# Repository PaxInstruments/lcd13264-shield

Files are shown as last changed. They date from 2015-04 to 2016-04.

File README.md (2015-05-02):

# Pax Instruments
# LCD12364-shield

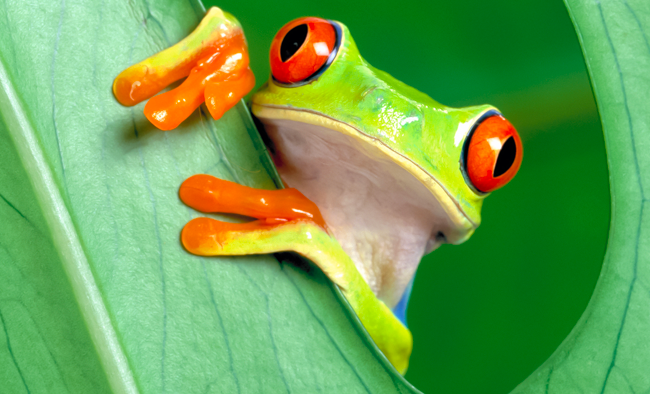
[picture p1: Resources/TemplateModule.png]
  
[Pax Instruments Template Module](<link to store page>)

## Overview
The Pax Instruments LCD12364-shield is an Arduino shield for the Pax Instruments LCD23164 graphic LCD. You can [purchase this item in our store](http://paxinstruments.com/products/sku1003/).

## Repository Contents
- __Datasheets__ - Datasheets for relevant components and parts
- __Electronics__ - All PCB and schematic design files
- __Enclosure__ - Enclosure 3D design files
- __Firmware__ - Firmware, libraries, and examples
- __Production__ - Manufacturing resources
- __Resources__ - Other resources

## Product Versions

## License Information
```
Place the license statement here
```

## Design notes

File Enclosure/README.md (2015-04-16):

# Pax Instruments
# LCD12364-shield Enclosure

Developed by <person(s) name> for [Pax Instruments](http://paxinstruments.com/), an original design.

## Overview
This is the enclsoure for the Pax Instruments LCD12364-shield designed in <software package>. STL files are included for your convenience.

## License
```
Place the license statement here
```

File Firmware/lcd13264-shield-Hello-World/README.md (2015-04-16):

# Pax Instruments
# LCD12364-shield Firmware

Developed by <person(s) name> for [Pax Instruments](http://paxinstruments.com/) based on Arduino and other Open Source libraries.

## Overview
There is no firmware required for the Pax Instruments LCD12364-shield.

## Required libraries
- Link to a forked Pax Instruments version
- of any  libraries used

## Installation
1. Copy libraryName into your <Arduino folder>/libraries/
2. Restart the ARduino IDE

## Example 1 - Hello, world!
```
void setup() {
    // The setup function. This runs once.
}

void loop() {
    // The loop function. This restarts when complete.
}
```

## History
__v0.2: 2015-02-22 by Charles Edward Pax__

- Major change 1
- Major change 2

__v0.1: 2015-02-20 by Charles Edward Pax__

- Major change 1
- Major change 2

## License
```
Place the license statement here
```

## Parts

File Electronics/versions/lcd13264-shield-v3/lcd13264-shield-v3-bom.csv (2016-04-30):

Qty | Value | Device | Package | Parts | Description | MPN | OC_DIGIKEY | PROD_ID | VALUE
1 |  | M08 | 1X08_ROUND | JP1 | Header 8
2 |  | TXB0104PWRSOIC14 | SO14 | U2, U3 | 4-Bit Bi-Directional Level Shifter |  |  | IC-11329
5 | 100nF | SPARKFUN-CAPACITORS_CAP0603-CAP | SPARKFUN-CAPACITORS_0603-CAP | C3, C4, C5, C6, C21 | Capacitor | CL10B104KO8NNNC | 1276-1005-2-ND
6 | 10k | SPARKFUN-RESISTORS_RESISTOR0603-RES | SPARKFUN-RESISTORS_0603-RES | R1, R8, R11, R12, R15, R16 | Resistor | RC1608J103CS | 1276-5086-2-ND
4 | 1uF | SPARKFUN-CAPACITORS_CAP0603-CAP | SPARKFUN-CAPACITORS_0603-CAP | C1, C2, C35, C36 | Capacitor | LMK107B7105KA-T | 587-1242-2-ND
2 | 3.3R | SPARKFUN-RESISTORS_RESISTOR0603-RES | SPARKFUN-RESISTORS_0603-RES | R2, R19 | Resistor
1 | ARDUINO_R3_SHIELDUNO_R3_SHIELD_NOLABELS_LOCK | ARDUINO_R3_SHIELDUNO_R3_SHIELD_NOLABELS_LOCK | UNO_R3_SHIELD_NOLABELS_LOCK | J3 | Shield form compatible with the Arduino Uno R3.
2 | FH12-12S-1S | FH12-12S-1S | FH12-12S-1SH | X1, X2
22 | JUMPER-PAD-2-NC_BY_PASTE | JUMPER-PAD-2-NC_BY_PASTE | PAD-JUMPER-2-NC_BY_PASTE_YES_SILK | SJ1, SJ2, SJ3, SJ4, SJ5, SJ6, SJ7, SJ8, SJ9, SJ10, SJ11, SJ12, SJ13, SJ14, SJ19, SJ20, SJ21, SJ22, SJ23, SJ24, SJ25, SJ26
1 | LG132643-DG | LG132643-DG | LG132643-DG | U$5 |  | LG132643-DW
1 | MICRO-SDCARD-CONNECTOR-3300060P1 | MICRO-SDCARD-CONNECTOR-3300060P1 | 9P-SMD-W-RING | J1 | Micro SD Card
1 | PNP-500mA | TRANSISTOR-PNP-DDTB142TC | SOT23-3 | Q1 | PNP transistor with base resistor. |  |  | TRANS-11479 | PNP-500mA
6 | SWITCH-MOMENTARY-2SMD | SWITCH-MOMENTARY-2SMD | TACTILE_SWITCH_SMD | S1, S2, S3, S4, S5, S6 | Various NO switches- pushbuttons, reed, etc

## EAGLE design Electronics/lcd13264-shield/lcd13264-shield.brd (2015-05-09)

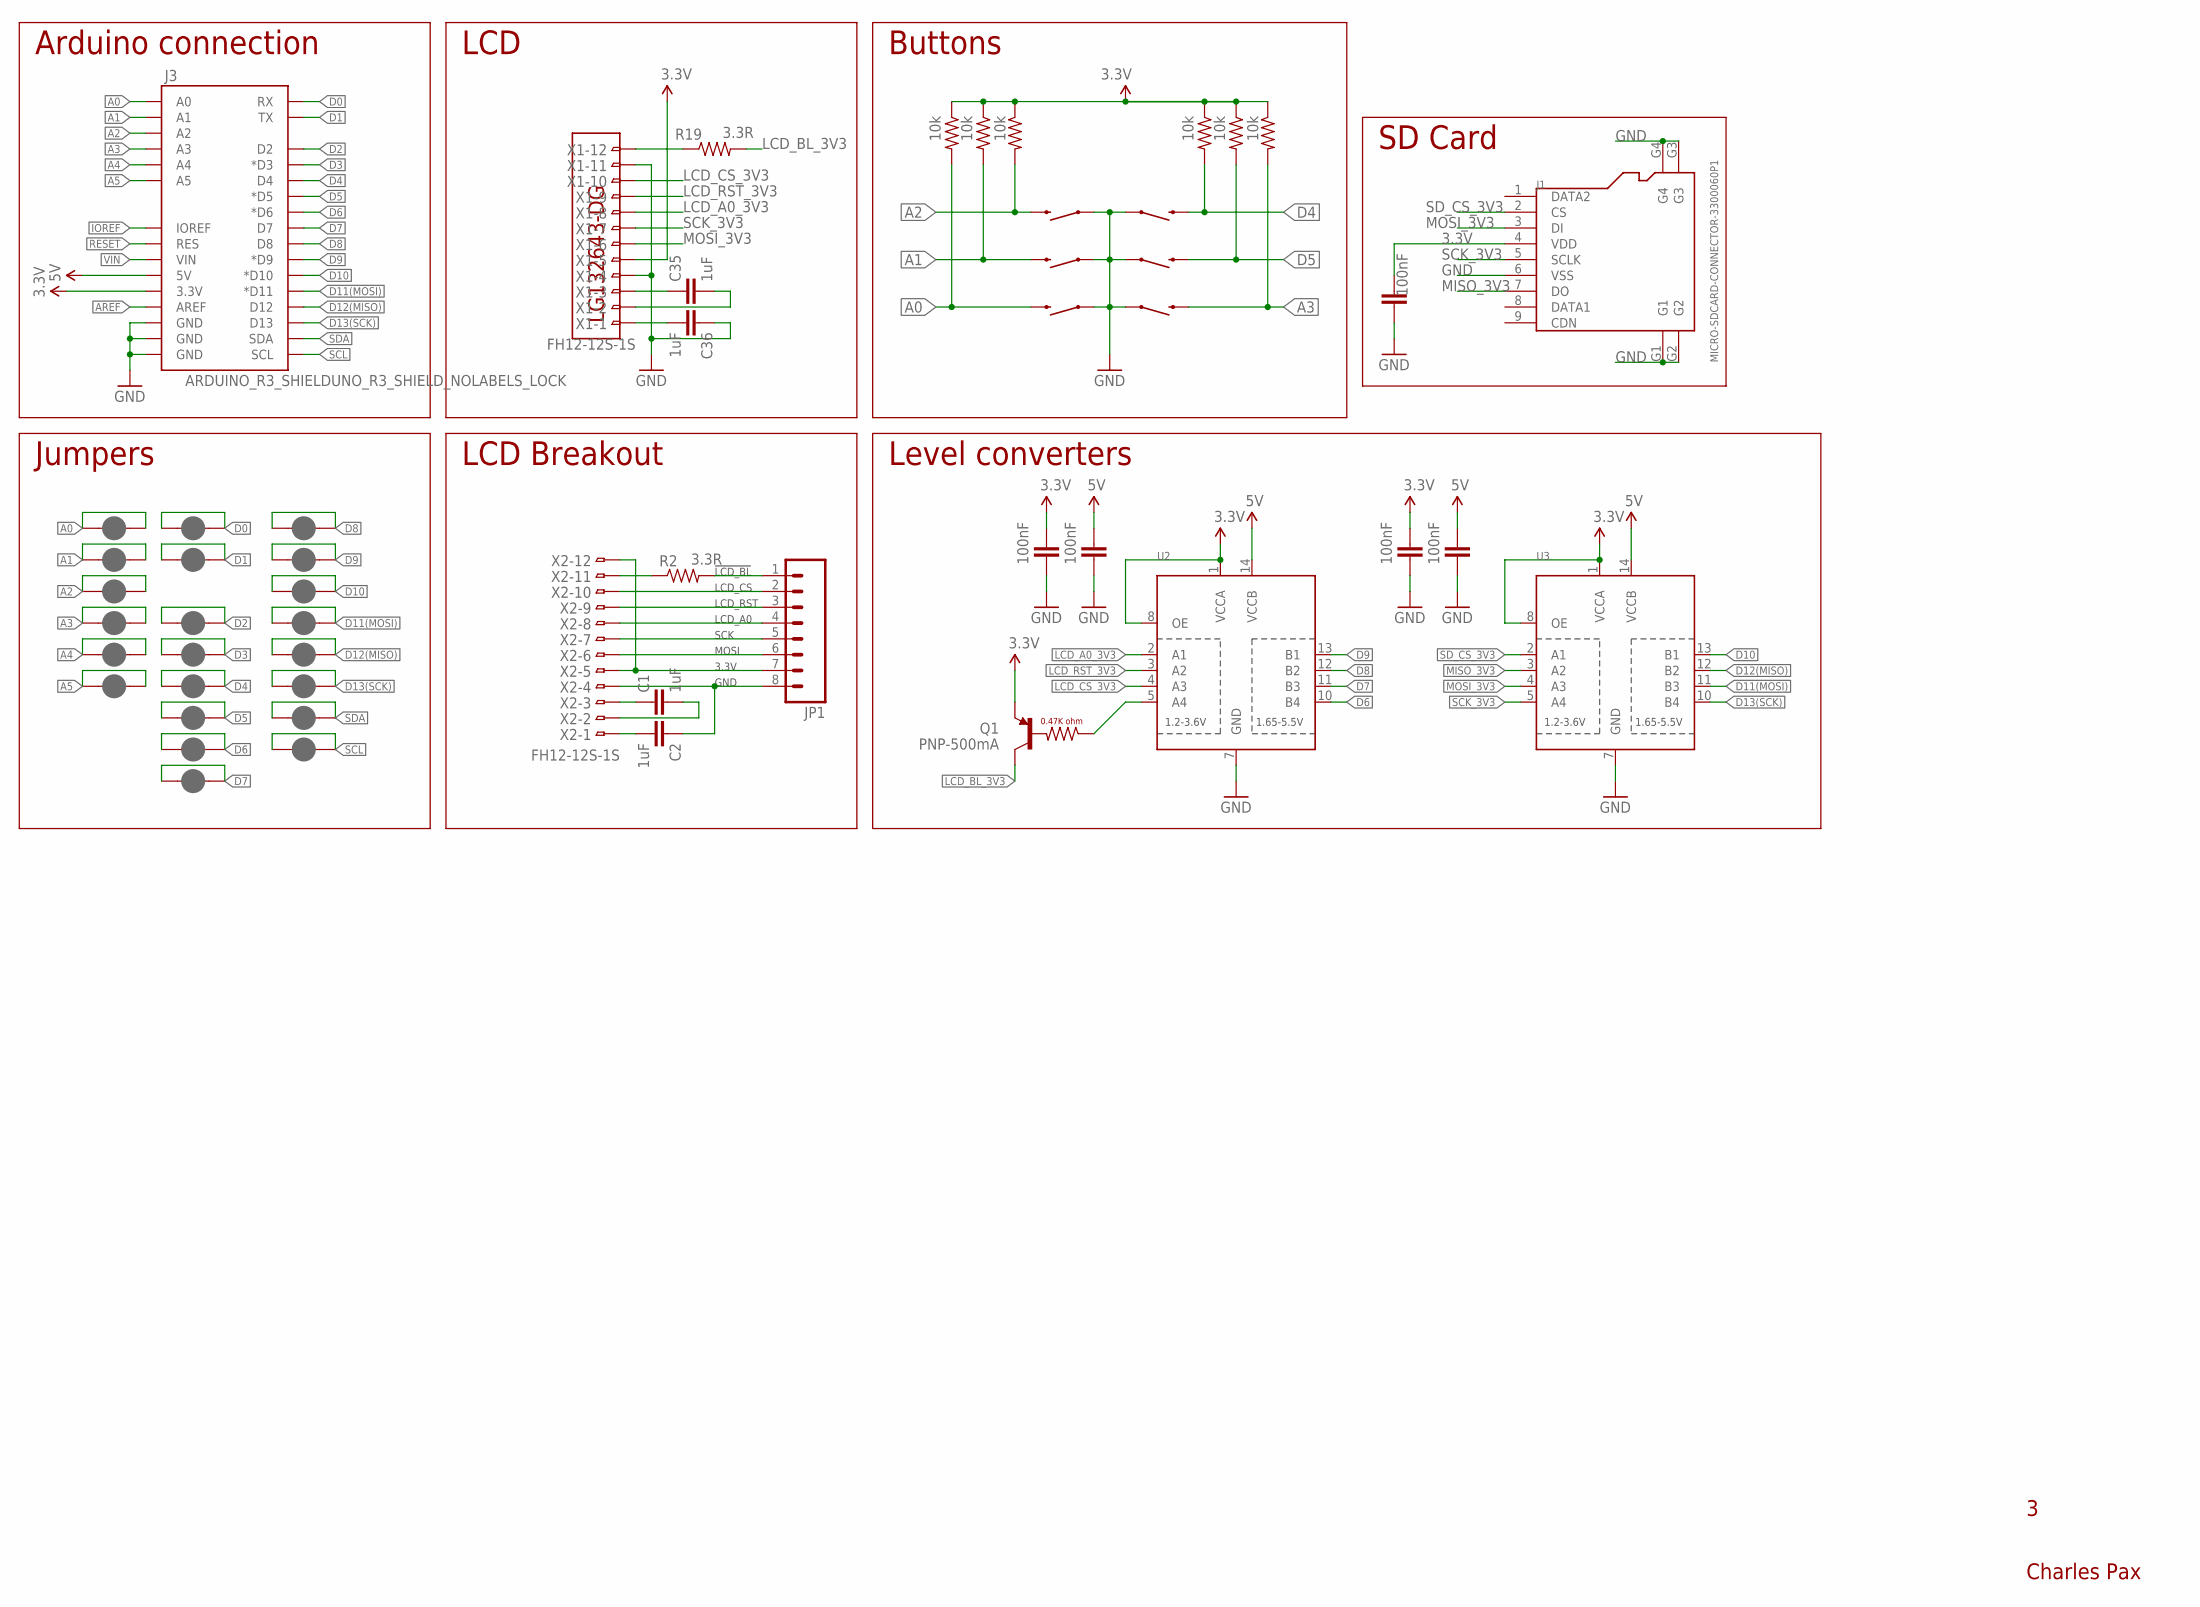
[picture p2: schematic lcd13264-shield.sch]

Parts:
C1, C2, C35, C36: 1uF; SPARKFUN-CAPACITORS_0603-CAP; MPN LMK107B7105KA-T
C3, C4, C5, C6, C21: 100nF; SPARKFUN-CAPACITORS_0603-CAP; MPN CL10B104KO8NNNC
J1: MICRO-SDCARD-CONNECTOR-3300060P1; 9P-SMD-W-RING
J3: ARDUINO_R3_SHIELDUNO_R3_SHIELD_NOLABELS_LOCK; UNO_R3_SHIELD_NOLABELS_LOCK
JP1: M08; 1X08_ROUND
Q1: PNP-500mA; SOT23-3; MPN DDTB142TC
R1, R8, R11, R12, R15, R16: 10k; SPARKFUN-RESISTORS_0603-RES; MPN RC1608J103CS
R2, R19: 3.3R; SPARKFUN-RESISTORS_0603-RES
S1, S2, S3, S4, S5, S6: SWITCH-MOMENTARY-2SMD; TACTILE_SWITCH_SMD
SJ1, SJ2, SJ3, SJ4, SJ5, SJ6, SJ7, SJ8, SJ9, SJ10, SJ11, SJ12, SJ13, SJ14, SJ19, SJ20, SJ21, SJ22, SJ23, SJ24, SJ25, SJ26: JUMPER-PAD-2-NC_BY_PASTE; PAD-JUMPER-2-NC_BY_PASTE_YES_SILK
U2, U3: TXB0104PWRSOIC14; SO14; MPN TXB0104DR
U$5: LG132643-DG; MPN LG132643-DW
X1, X2: FH12-12S-1S; FH12-12S-1SH

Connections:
3.3V: C3.2, C5.2, C21.2, J1.4 (VDD), J3.3.3V, Q1.2 (E), R1.1, R8.1, R11.1, R12.1, R15.1, R16.1, U2.1 (VCCA), U2.8 (OE), U3.1 (VCCA), U3.8 (OE), X1.5
5V: C4.2, C6.2, J3.5V, U2.14 (VCCB), U3.14 (VCCB)
A0: J3.A0, R1.2, S6.3 (2), SJ10.1, SJ10.2
A1: J3.A1, R16.2, S5.3 (2), SJ7.1, SJ7.2
A2: J3.A2, R15.2, S4.3 (2), SJ11.1, SJ11.2
A3: J3.A3, R12.2, S1.3 (2), SJ12.1, SJ12.2
A4: J3.A4, SJ13.1, SJ13.2
A5: J3.A5, SJ14.1, SJ14.2
AREF: J3.AREF
D0: J3.RX, SJ8.1, SJ8.2
D1: J3.TX, SJ9.1, SJ9.2
D2: J3.D2, SJ3.1, SJ3.2
D3: J3.D3 (*D3), SJ4.1, SJ4.2
D4: J3.D4, R8.2, S3.3 (2), SJ5.1, SJ5.2
D5: J3.D5 (*D5), R11.2, S2.3 (2), SJ6.1, SJ6.2
D6: J3.D6 (*D6), SJ19.1, SJ19.2, U2.10 (B4)
D7: J3.D7, SJ20.1, SJ20.2, U2.11 (B3)
D8: J3.D8, SJ21.1, SJ21.2, U2.12 (B2)
D9: J3.D9 (*D9), SJ22.1, SJ22.2, U2.13 (B1)
D10: J3.D10 (*D10), SJ23.1, SJ23.2, U3.13 (B1)
D11(MOSI): J3.D11 (*D11), SJ24.1, SJ24.2, U3.11 (B3)
D12(MISO): J3.D12, SJ25.1, SJ25.2, U3.12 (B2)
D13(SCK): J3.D13, SJ26.1, SJ26.2, U3.10 (B4)
GND: C2.1, C3.1, C4.1, C5.1, C6.1, C21.1, C36.1, J1.6 (VSS), J1.G1, J1.G2, J1.G3, J1.G4, J3.GND@0 (GND), J3.GND@1 (GND), J3.GND@2 (GND), JP1.8, S1.1, S2.1, S3.1, S4.1, S5.1, S6.1, U2.7 (GND), U3.7 (GND), X1.4, X1.11, X2.4
IOREF: J3.IOREF
LCD_A0_3V3: U2.2 (A1), X1.8
LCD_BL_3V3: Q1.3 (C), R19.2
LCD_CS_3V3: U2.4 (A3), X1.10
LCD_RST_3V3: U2.3 (A2), X1.9
MISO_3V3: J1.7 (DO), U3.3 (A2)
MOSI_3V3: J1.3 (DI), U3.4 (A3), X1.6
unnamed: R19.1, X1.12
unnamed: C35.1, X1.3
unnamed: C35.2, X1.2
unnamed: C36.2, X1.1
unnamed: C1.1, X2.3
unnamed: C1.2, X2.2
unnamed: C2.2, X2.1
unnamed: R2.1, X2.11
unnamed: JP1.7, X2.5, X2.12
unnamed: JP1.1, R2.2
unnamed: JP1.2, X2.10
unnamed: JP1.3, X2.9
unnamed: JP1.4, X2.8
unnamed: JP1.5, X2.7
unnamed: JP1.6, X2.6
unnamed: Q1.1 (B), U2.5 (A4)
RESET: J3.RES
SCK_3V3: J1.5 (SCLK), U3.5 (A4), X1.7
SCL: J3.SCL, SJ2.1, SJ2.2
SDA: J3.SDA, SJ1.1, SJ1.2
SD_CS_3V3: J1.2 (CS), U3.2 (A1)
VIN: J3.VIN

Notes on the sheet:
LCD
Buttons
Charles Pax
SD Card
Arduino connection
LCD Breakout
GND
3.3V
MOSI
SCK
LCD_A0
LCD_RST
LCD_CS
!LCD_BL
Level converters
Jumpers

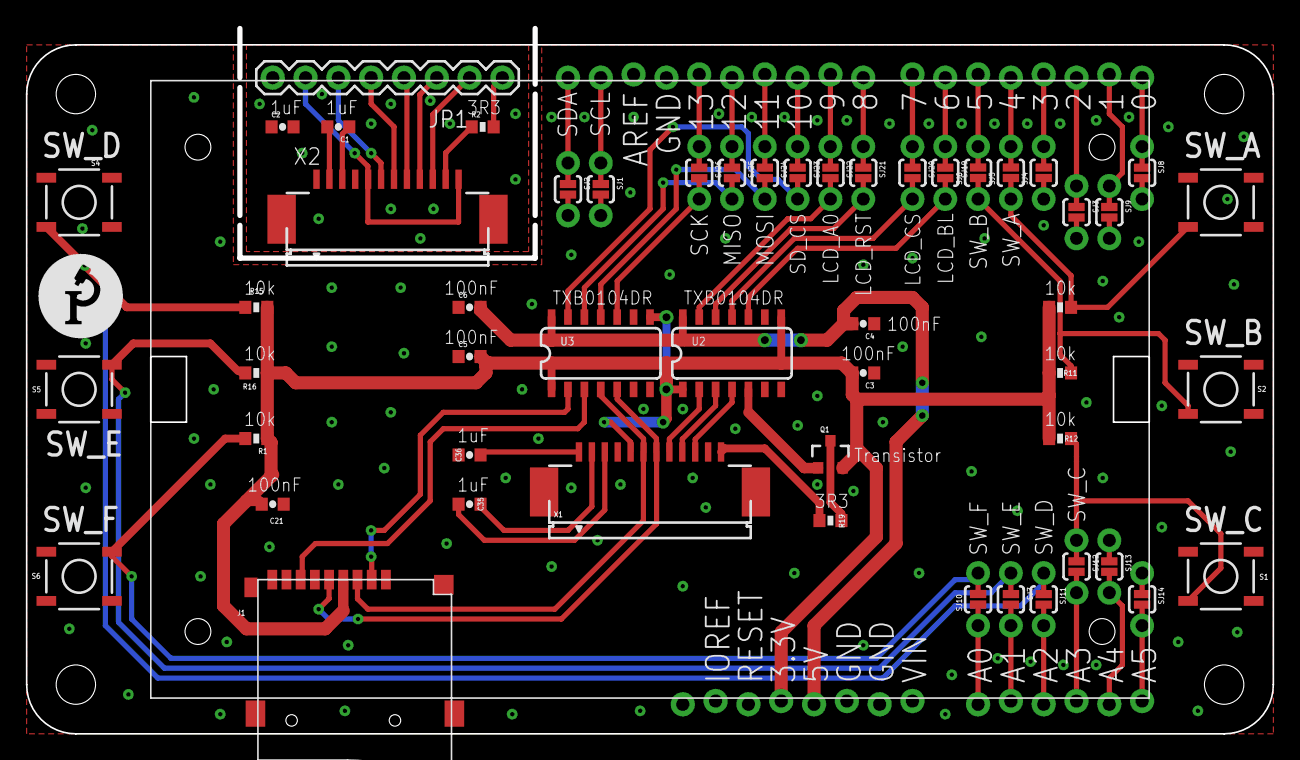
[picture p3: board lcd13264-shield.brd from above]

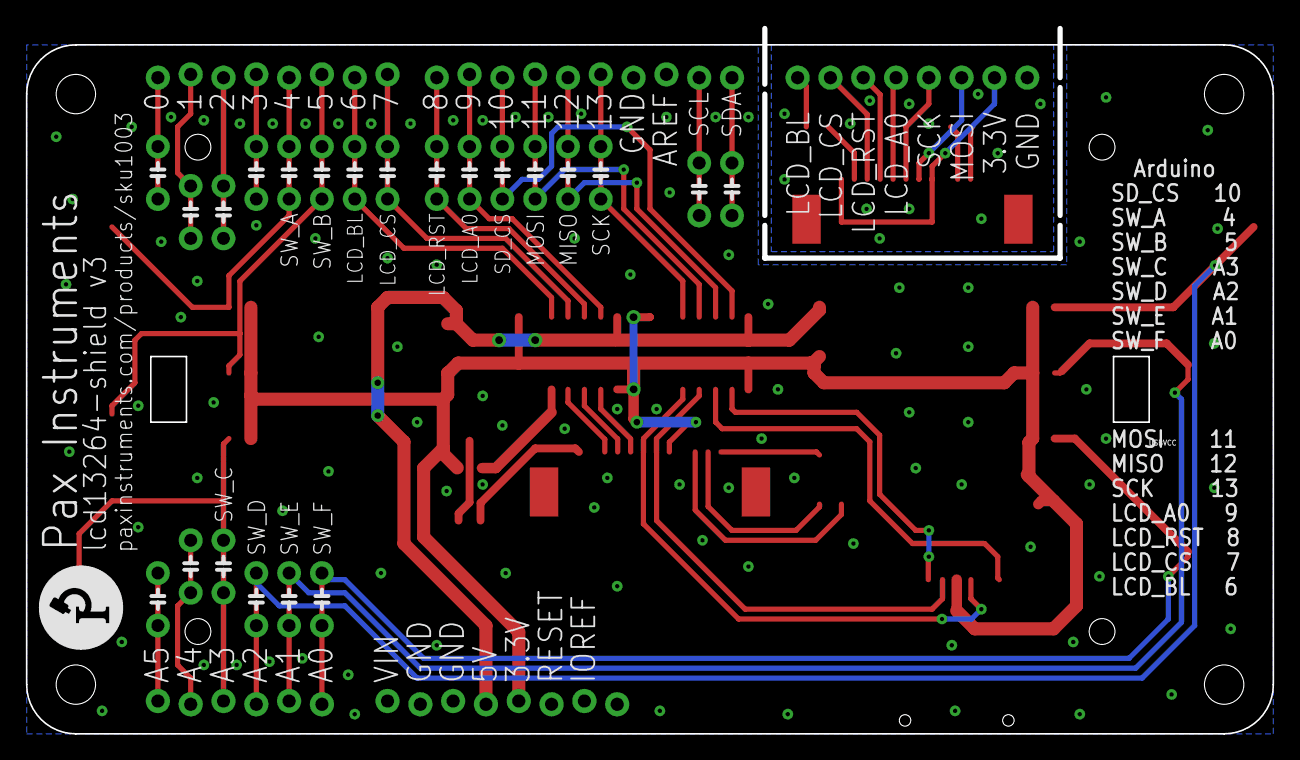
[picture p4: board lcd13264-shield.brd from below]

Board: 2 copper layers, 96.5 x 54.6 mm, 56 parts (2 on the bottom side), 49 nets.

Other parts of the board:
U$1, U$6: PAXINSTRUMENT_LOGO

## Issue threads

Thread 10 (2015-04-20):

Arduino footprint marking information

charlespax, 2015-04-20:
Make an Arduino shield footprint that only marks the location of holes and describes things. This would not be rendered in any way on the gerber files.

This will be helpful when moving to the jumpers rather than a complete Arduino footprint with silkscreen. See https://github.com/PaxInstruments/lcd13264-shield/issues/6

charlespax, 2015-04-26:
Design has Arduino pin markings.

Closed 2015-04-26.

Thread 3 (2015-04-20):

Header interference

charlespax, 2015-04-20:
Rotate the extra breakout board 1008 degrees, so the header can be soldered into place without interfering with the Arduino USB connector.
![Uploading Screen Shot 2015-04-20 at 16.33.38.png . . .]()

charlespax, 2015-04-20:
Done. Closing.

Closed 2015-04-20.

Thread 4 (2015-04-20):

Connection labels

charlespax, 2015-04-20:
Add a table to the silkscreen that correlates the Arduino pins with the shield functions.

Here is what they are in the schematic.
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

We can also label the pins with their function.
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

charlespax, 2015-04-20:
We can put this in a place that can be viewed while the shield is plugged into an Arduino.

charlespax, 2015-04-26:
Each IO pin has a label. There is a pin map table on the silkscreen.

Closed 2015-04-26.

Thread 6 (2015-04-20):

Pin configuration jumpers

charlespax, 2015-04-20:
It would be great if there were jumpers such that users have some degree of freedom to configure which pins are connected to which devices. We can place jumpers and extra through hole vias next to each arduino pin on the shield. The user can cut the trace and solder a jumper wire to their desired pin.

It would be cool if there were a nice place on the silkscreen where the user can write their new pin configuration.

charlespax, 2015-04-20:
Use these jumpers.

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

charlespax, 2015-04-26:
All I/O pins have jumpers.

Closed 2015-04-26.

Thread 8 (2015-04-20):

Symmetry

charlespax, 2015-04-20:
The arduinio can be made more symmetric on the shield. It looks like the top and bottom standoff tabs do not interfere with the pin headers.

charlespax, 2015-04-26:
I moved the Arduino such that mounting holes can go in the corners.

Closed 2015-04-26.

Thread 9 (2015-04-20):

Prototyping area

charlespax, 2015-04-20:
Add some through-hole and SMD prototyping pads to both sides of the PCB.

charlespax, 2015-04-26:
Meh. Ice boxing...

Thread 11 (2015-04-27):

Silkscreen issues

charlespax, 2015-04-27:
The logo overlaps the pin map. Move logo left.
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

Product name is on a hole. The P in Pax Instruments may be too close to the milled slot
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

Breakout board labels cover each other and on is on a solder pad.
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

The LCD connector and transistor are not labelled.
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

There is an old USBVCC label on the silkscreen.
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

Add labels to the breakout board bottom.
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

We have the room, so we may as well label the bottom side Arduino pins.
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

We can add drawings to the bottom to indicate how the pins are connected.
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

We should indicate the pin map is for Arduino pins.
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

Add lines to indicate which pads are for the same component. It could be confusing for beginners.
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

The pin map may be too close to the milled slot.
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

We should add function labels to the silkscreen.
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

charlespax, 2015-05-02:
Many of these problems are from Eagle using a proportional font in the interface, but a vector font in the CAM processor. See http://forum.sunstone.com/eagle-text-does-not-look-the-same-on-the-screen-and-pcb-t81.html.

charlespax, 2015-05-02:
Done.

Closed 2015-05-02.

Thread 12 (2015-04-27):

Transistor size

charlespax, 2015-04-27:
Maybe we should increase the resistor size. This would make it easier to solder.
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

charlespax, 2015-05-02:
Let's keep the size we have. People are soldering 0603 parts anyway.

Closed 2015-05-02.

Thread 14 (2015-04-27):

Breakout board snaps

charlespax, 2015-04-27:
This links between the breakout board and shield should be a hair smaller

charlespax, 2015-05-02:
Done.

Closed 2015-05-02.

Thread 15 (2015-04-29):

Update footprints

charlespax, 2015-04-29:
Make sure all the footprints are up-to-date. This specifically affects the LCD connector.

charlespax, 2015-05-02:
It looks like the LCD connector is up to date.

Closed 2015-05-02.

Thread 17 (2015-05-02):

Expose Arduino ports to putside world

charlespax, 2015-05-02:
We can move the Arduino board to an edge such that the shield and Arduino can be put into an enclosure and have the SD, USB, and power ports open to the outside.

Ice boxing...

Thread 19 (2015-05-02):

Hole in logo

charlespax, 2015-05-02:
The rendering of version 3 has a big via going right through the logo. We should move this.
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

charlespax, 2015-05-03:
Not a problem. Maybe fix in the next version. Ice Box.

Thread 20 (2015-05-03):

Backlight active low

charlespax, 2015-05-03:
The backlight is active the LCD_BL is low. It would be nicer if this were active high.

charlespax, 2015-05-03:
It works. Maybe we can change this in the next version, but I think having two versions of the same product is worse than an active low backlight. Ice box.

charlespax, 2015-05-05:
In v3 we are using a PNP transistor with built-in base resistor.

The breakout connector is set to active low because microcontrollers tend to be able to sink more current than they can source on a given pin. This makes the breakout board and the shield consistent. I think this is good. Closing issue.

Closed 2015-05-05.

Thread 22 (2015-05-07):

Milled LCD slots

charlespax, 2015-05-07:
In the most recent batch of PCBs the LCD clip slots had rounded corners of a much larger radius than before. This interferes with the clip slightly. We'll have to file the corners by hand. The slot was also plated this time. previously, it was not.

Let's learn exactly how to call this out in the schematic to have the board house make a consistent product.

The next revision should have a square outline layer in the slot area.

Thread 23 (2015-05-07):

LCD breakout board

charlespax, 2015-05-07:
The LCD connector on the breakout board can be broken off when the breakout board is snapped out of the shield. This is because the connector overhangs the shield slightly. This only happens when snapped out from front to back. From back to font it is fine.

We should move the milled slot out a bit.

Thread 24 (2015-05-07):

LCD interferes with connectors

charlespax, 2015-05-07:
Let's move the LCD down a bit such that the standoff at the middle top does not interfere with headers.

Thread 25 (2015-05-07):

LCD breakout board headers location

charlespax, 2015-05-07:
Maybe we can move this a bit. The headers pins are pretty close to the Arduino reset switch

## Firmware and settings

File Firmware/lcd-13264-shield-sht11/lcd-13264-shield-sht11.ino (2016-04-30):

/*

  HelloWorld.pde
  
  "Hello World!" example code.
  
  >>> Before compiling: Please remove comment from the constructor of the 
  >>> connected graphics display (see below).
  
  Universal 8bit Graphics Library, http://code.google.com/p/u8glib/
  
  Copyright (c) 2012, olikraus@gmail.com
  All rights reserved.

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
  THIS SOFTWARE IS PROVIDED BY THE COPYRIGHT HOLDERS AND 
  CONTRIBUTORS "AS IS" AND ANY EXPRESS OR IMPLIED WARRANTIES, 
  INCLUDING, BUT NOT LIMITED TO, THE IMPLIED WARRANTIES OF 
  MERCHANTABILITY AND FITNESS FOR A PARTICULAR PURPOSE ARE 
  DISCLAIMED. IN NO EVENT SHALL THE COPYRIGHT HOLDER OR 
  CONTRIBUTORS BE LIABLE FOR ANY DIRECT, INDIRECT, INCIDENTAL, 
  SPECIAL, EXEMPLARY, OR CONSEQUENTIAL DAMAGES (INCLUDING, BUT 
  NOT LIMITED TO, PROCUREMENT OF SUBSTITUTE GOODS OR SERVICES; 
  LOSS OF USE, DATA, OR PROFITS; OR BUSINESS INTERRUPTION) HOWEVER 
  CAUSED AND ON ANY THEORY OF LIABILITY, WHETHER IN CONTRACT, 
  STRICT LIABILITY, OR TORT (INCLUDING NEGLIGENCE OR OTHERWISE) 
  ARISING IN ANY WAY OUT OF THE USE OF THIS SOFTWARE, EVEN IF 
  ADVISED OF THE POSSIBILITY OF SUCH DAMAGE.  
  
*/

// This documen is modified to work with the Pax Instruments LCD Test Board v0.2
#define LCD_A0               9
#define LCD_BACKLIGHT_PIN    6    // LCD backlight on pin
#define LCD_CS               7
#define LCD_RST              8
// MISO                     14
// SCK                      15
// MOSI                     16
#define SW_A_pin             4
#define SW_B_pin             5
#define SW_C_pin             A3
#define SW_D_pin             A2
#define SW_E_pin             A1
#define SW_F_pin             A0
#define SD_CS                10

#define LCD_CONTRAST     0x018*7  // Sets the LCD contrast

#define DHTPIN A4     // what pin we're connected to
#define DHTTYPE DHT11   // DHT 11 

#include "U8glib.h"
#include <SdFat.h>
#include "DHT.h"

U8GLIB_PI13264  u8g(LCD_CS, LCD_A0, LCD_RST); // Use HW-SPI

DHT dht(DHTPIN, DHTTYPE);

SdFat sd;
SdFile myFile;
int sd_test_status = 0;

int SW_A_state = 0;
int SW_B_state = 0;
int SW_C_state = 0;
int SW_D_state = 0;
int SW_E_state = 0;
int SW_F_state = 0;

int fadeValue = 0;
int updown = 1; // is the fading going up or down

int sdTest(){
//  Serial.begin(9600);
//  while (!Serial) {}  // wait for Leonardo
//  Serial.println("Type any character to start");
//  while (Serial.read() <= 0) {}
//  delay(400);  // catch Due reset problem
 // if (sd.begin(SD_CS, SPI_HALF_SPEED)) sd.initErrorHalt();
  sd.begin(SD_CS, SPI_HALF_SPEED);
  if (!myFile.open("testFile.txt", O_RDWR | O_CREAT | O_AT_END)) {
    //sd.errorHalt("opening test.txt for write failed");
    return 0;
  }
//  Serial.print("Writing to test.txt...");
  myFile.println("testing 1, 2, 3.");
  myFile.close();
//  Serial.println("done.");
  if (!myFile.open("test.txt", O_READ)) {
   // sd.errorHalt("opening test.txt for read failed");
    return 0;
  }
//  Serial.println("test.txt:");
  int data;
  while ((data = myFile.read()) >= 0) Serial.write(data);
  // close the file:
  myFile.close();
  return 1;
}

void draw(void) {
  // graphic commands to redraw the complete screen should be placed here  
  //u8g.setFont(u8g_font_unifont);
  u8g.setFont(u8g_font_ncenR12);
  u8g.drawStr( 0, 14, "PAX");
  u8g.drawStr( 0, 30, "INSTRUMENTS");
  
  u8g.setFont(u8g_font_5x8);
  u8g.drawStr( 0, 39, "OPENSOURCE LAB INSTRUMENTS");
  u8g.drawStr( 0, 62, "Graphic LCD 132x64 shield");
  u8g.drawStr( 40, 8, "    Temp: ");
  u8g.setPrintPos(90, 8);
  u8g.print(dht.readTemperature(), 0);
  u8g.drawStr( 100, 8, " C");
  u8g.drawStr( 40, 16, "Humidity: ");
  u8g.setPrintPos(90, 16);
  u8g.print(dht.readHumidity(), 0);
  u8g.drawStr( 100, 16, " %");
  
  
  // Draw button stuff
  if (SW_A_state == LOW) {     
    u8g.drawStr( 0, 50, "A");
  } 
  if (SW_B_state == LOW) {     
    u8g.drawStr( 5, 50, "B");
  } 
  if (SW_C_state == LOW) {     
    u8g.drawStr( 10, 50, "C");
  } 
  if (SW_D_state == LOW) {     
    u8g.drawStr( 15, 50, "D");
    if (SW_C_state == LOW){
      if (sd_test_status == 0){
        u8g.drawStr( 75, 50, "SD: bad");
      }
      if (sd_test_status == 1){
        u8g.drawStr( 75, 50, "SD: okay");
      }
    }
  } 
  if (SW_E_state == LOW) {     
    u8g.drawStr( 20, 50, "E");
  } 
  if (SW_F_state == LOW) {     
    u8g.drawStr( 25, 50, "Fading...");
  } 
}

void setup(void) {
  sd_test_status = sdTest();
    // flip screen, if required
  u8g.setRot180();
  u8g.setContrast(LCD_CONTRAST);
  
  pinMode(LCD_BACKLIGHT_PIN, OUTPUT);           
  analogWrite(LCD_BACKLIGHT_PIN, fadeValue);   

  // assign default color value
  if ( u8g.getMode() == U8G_MODE_R3G3B2 ) {
    u8g.setColorIndex(255);     // white
  }
  else if ( u8g.getMode() == U8G_MODE_GRAY2BIT ) {
    u8g.setColorIndex(3);         // max intensity
  }
  else if ( u8g.getMode() == U8G_MODE_BW ) {
    u8g.setColorIndex(1);         // pixel on
  }
  else if ( u8g.getMode() == U8G_MODE_HICOLOR ) {
    u8g.setHiColorByRGB(255,255,255);
  }
  
  // Set up the buttons
    pinMode(SW_A_pin, INPUT);
    pinMode(SW_B_pin, INPUT);
    pinMode(SW_C_pin, INPUT);
    pinMode(SW_D_pin, INPUT);
    pinMode(SW_E_pin, INPUT);
    pinMode(SW_F_pin, INPUT);
    
    dht.begin();
}



void loop(void) {
  SW_A_state = digitalRead(SW_A_pin);
  SW_B_state = digitalRead(SW_B_pin);
  SW_C_state = digitalRead(SW_C_pin);
  SW_D_state = digitalRead(SW_D_pin);
  SW_E_state = digitalRead(SW_E_pin);
  SW_F_state = digitalRead(SW_F_pin);
  
  // fade in from min to max in increments of 5 points:

  if (SW_D_state == false && SW_C_state == false){
   sd_test_status = sdTest(); 
  }
  
  // picture loop
  u8g.firstPage();  
  do {
    draw();
  }
  while( u8g.nextPage() );
  // rebuild the picture after some delay
  delay(50);
  while(SW_F_state == false){
    if (fadeValue >=255){
      updown = 0;
    }
    if (fadeValue <= 0 ){
      updown = 1;
    }
    
    analogWrite(LCD_BACKLIGHT_PIN, fadeValue);         
    delay(3);
    if (updown == true){
      fadeValue +=1;
    }
    if (updown == false){
      fadeValue -=1;
    }
    SW_F_state = digitalRead(SW_F_pin);
  }
}

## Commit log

2015-04-16 Initial commit.
    [lcd13264-shield.brd, lcd13264-shield.sch]
2015-04-16 Routed baord. Need to put on finishing touches.
    [lcd13264-shield.brd, lcd13264-shield.sch]
2015-04-16 Revied and modified PCB for ordering. Initiated a v1 version. Added CAM file.
    [CopperBottom.GBL, CopperTop.GTL, Dimension.GKO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]
2015-04-18 Updated the LCD connector.
    [lcd13264-shield.brd, lcd13264-shield.sch]
2015-04-20 Added component tags to PCB (more needed). Added firmware.
    [lcd13264-shield.brd]
2015-04-20 Firmware tests each button, prints to LCD, and fades the backlight.
2015-04-20 Added bypass caps to level shifter. This closes #1.
    [lcd13264-shield.brd, lcd13264-shield.sch]
2015-04-22 Aupdated shield. Not sure what.
    [lcd13264-shield.brd, lcd13264-shield.sch]
2015-04-26 Close to done. Need to review.
    [lcd13264-shield.brd, lcd13264-shield.sch]
2015-04-26 This version is done. CAM next...
    [lcd13264-shield.brd, lcd13264-shield.sch]
2015-04-26 Added v2 gerber files.
    [lcd13264-shield.brd, lcd13264-shield.sch]
2015-05-02 Changed all passives to 0805 and updated traces. Passes DRC.
    [lcd13264-shield.brd, lcd13264-shield.sch]
2015-05-02 Decreased breakout board snap size.
    [lcd13264-shield.brd]
2015-05-02 Reorganized the versions gerbers.
    [CopperBottom.GBL, CopperTop.GTL, Dimension.GKO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]
2015-05-02 Renamed some files.
    [lcd13264-shield.brd, lcd13264-shield.sch]
2015-05-02 Closed all the silkscreen issues.
    [lcd13264-shield.brd, lcd13264-shield.sch]
2015-05-02 Added pin function labels to top and bottom. Verified silkscreen.
    [lcd13264-shield.brd, lcd13264-shield.sch]
2015-05-02 Added version 3 gerbers.
    [lcd13264-shield.brd, lcd13264-shield.sch]
2015-05-03 Added MPN for LCD_BL PNP transistor.
    [lcd13264-shield.brd, lcd13264-shield.sch]
2015-05-05 Corrected the transistor value. We are using a transistor with built-in base resistor.
    [lcd13264-shield.brd, lcd13264-shield.sch]
2015-05-05 Added active low notation to LCD_BL.
    [lcd13264-shield.sch]
2015-05-09 Added psrt numbers.
    [lcd13264-shield.brd, lcd13264-shield.sch]
2016-04-30 Unknown changes.
    [CopperBottom.GBL, CopperTop.GTL, Dimension.GKO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]

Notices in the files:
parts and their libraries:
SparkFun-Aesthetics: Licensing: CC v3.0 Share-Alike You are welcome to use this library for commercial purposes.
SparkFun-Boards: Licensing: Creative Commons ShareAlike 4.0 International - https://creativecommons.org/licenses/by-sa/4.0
